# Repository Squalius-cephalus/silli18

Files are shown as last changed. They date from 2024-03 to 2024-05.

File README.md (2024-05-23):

# Silli18
RP2040 based macropad, which uses [QMK](https://github.com/qmk/qmk_firmware) firmware with [Vial](https://get.vial.today/) support. 

If you are interested in macropad with hotswap sockets, check [Silakka18](https://github.com/Squalius-cephalus/silakka18).

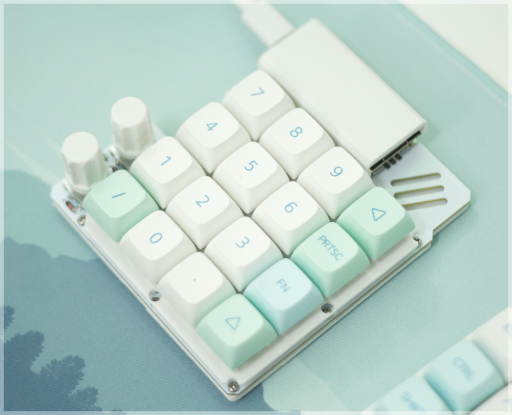
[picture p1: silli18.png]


## Bill of materials

 - 1 x PCB
 - 1 x Pin compatible Raspberry Pi Pico
 - 1 x 3D printed bottom plate
 - 1 x 3D printed top plate
 - 2 x EC11 Rotary encoders
 - 16 x MX style mechanical switches
 - 16 x MX compatible keycaps
 - 18 x 1N4148 diode
 - 8 x M2 4mm bolt
 - 8 x M2 brass inserts 
 - 8x Rubber feet

## TODO

 1. Make build guide

PCB design uses footprints from [ScottoKeebs](https://github.com/joe-scotto/scottokeebs/tree/main/Extras/ScottoKicad "ScottoKeebs") and [kbd library.](https://github.com/foostan/kbd "kbd library.")

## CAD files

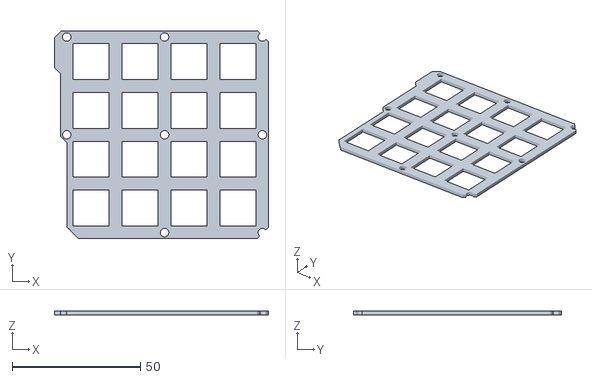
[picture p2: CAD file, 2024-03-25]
stl/top.stl
83.3 x 81.2 x 1.60

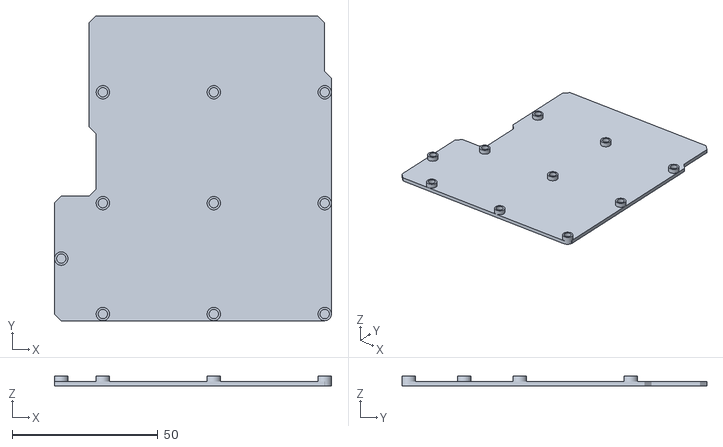
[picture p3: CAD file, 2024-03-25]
stl/bottom.stl
95.3 x 104.8 x 3.60

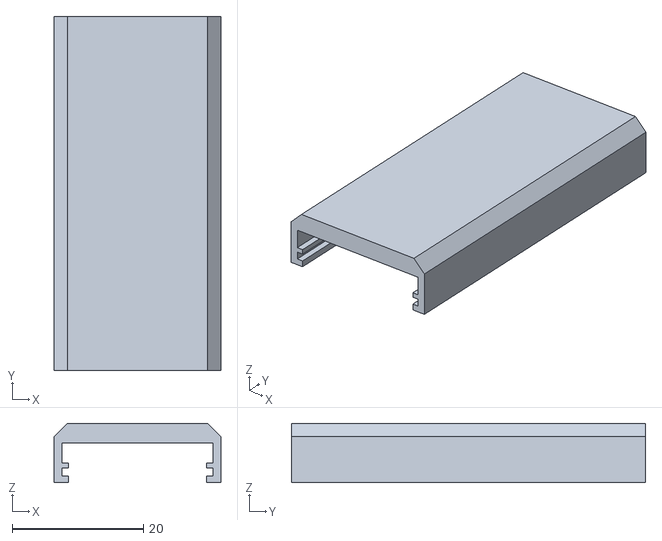
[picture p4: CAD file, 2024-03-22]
stl/raspberry_pi_pico_cover.stl
25.4 x 54.0 x 9.00

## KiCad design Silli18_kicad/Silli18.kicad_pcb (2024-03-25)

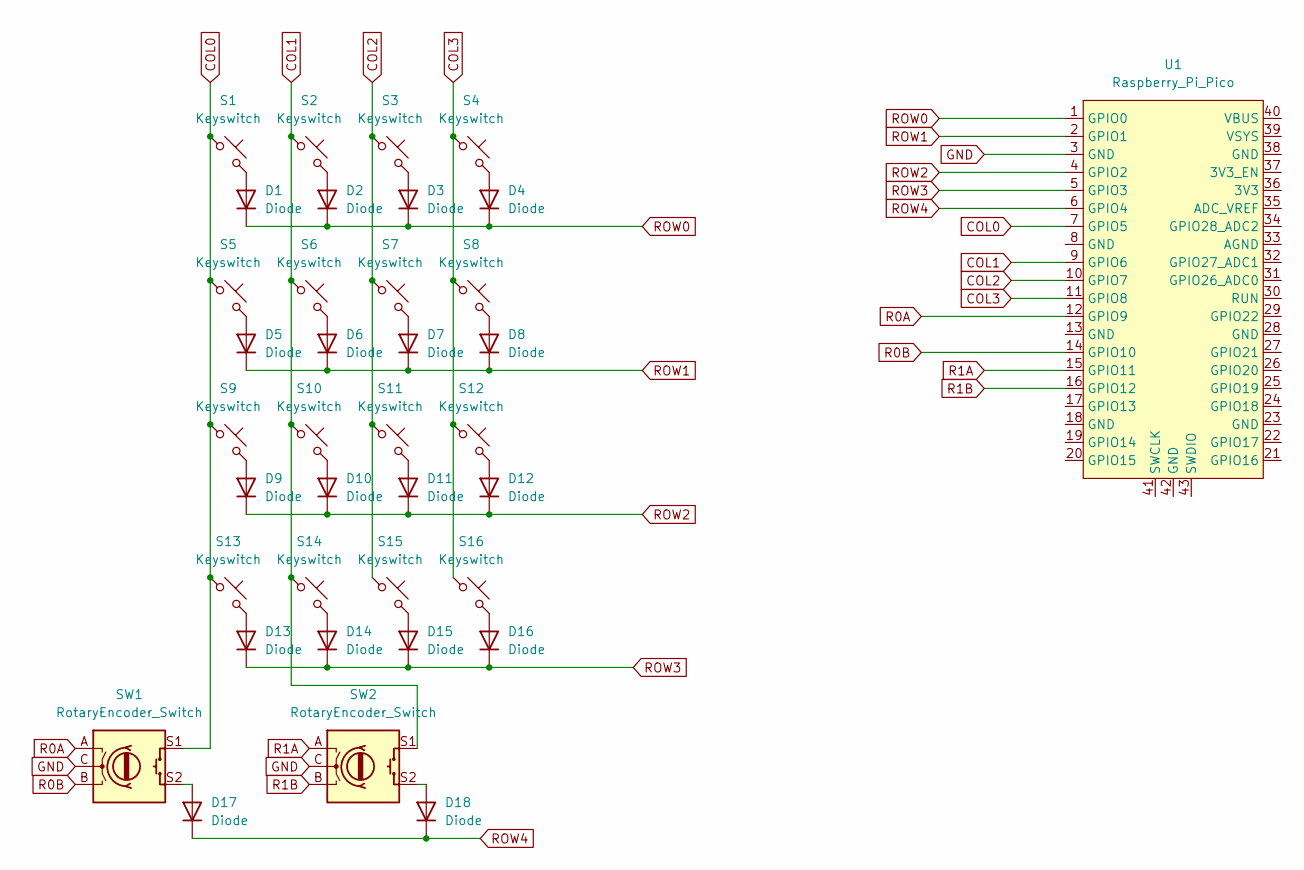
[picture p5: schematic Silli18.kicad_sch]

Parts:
D1, D2, D3, D4, D5, D6, D7, D8, D9, D10, D11, D12, D13, D14, D15, D16, D17, D18: Diode; D3_TH
S1, S2, S3, S4, S5, S6, S7, S8, S9, S10, S11, S12, S13, S14, S15, S16: Keyswitch; MX_PCB_1.00u
SW1, SW2: RotaryEncoder_Switch; RotaryEncoder_EC11
U1: Raspberry_Pi_Pico

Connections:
COL0: S1.1, S5.1, S9.1, S13.1, SW1.S1, U1.7 (GPIO5)
COL1: S2.1, S6.1, S10.1, S14.1, SW2.S1, U1.9 (GPIO6)
COL2: S3.1, S7.1, S11.1, S15.1, U1.10 (GPIO7)
COL3: S4.1, S8.1, S12.1, S16.1, U1.11 (GPIO8)
GND: SW1.C, SW2.C, U1.3 (GND)
unnamed: D1.2 (A), S1.2
unnamed: D2.2 (A), S2.2
unnamed: D3.2 (A), S3.2
unnamed: D4.2 (A), S4.2
unnamed: D5.2 (A), S5.2
unnamed: D6.2 (A), S6.2
unnamed: D7.2 (A), S7.2
unnamed: D8.2 (A), S8.2
unnamed: D9.2 (A), S9.2
unnamed: D10.2 (A), S10.2
unnamed: D11.2 (A), S11.2
unnamed: D12.2 (A), S12.2
unnamed: D13.2 (A), S13.2
unnamed: D14.2 (A), S14.2
unnamed: D15.2 (A), S15.2
unnamed: D16.2 (A), S16.2
unnamed: D17.2 (A), SW1.S2
unnamed: D18.2 (A), SW2.S2
R0A: SW1.A, U1.12 (GPIO9)
R0B: SW1.B, U1.14 (GPIO10)
R1A: SW2.A, U1.15 (GPIO11)
R1B: SW2.B, U1.16 (GPIO12)
ROW0: D1.1 (K), D2.1 (K), D3.1 (K), D4.1 (K), U1.1 (GPIO0)
ROW1: D5.1 (K), D6.1 (K), D7.1 (K), D8.1 (K), U1.2 (GPIO1)
ROW2: D9.1 (K), D10.1 (K), D11.1 (K), D12.1 (K), U1.4 (GPIO2)
ROW3: D13.1 (K), D14.1 (K), D15.1 (K), D16.1 (K), U1.5 (GPIO3)
ROW4: D17.1 (K), D18.1 (K), U1.6 (GPIO4)

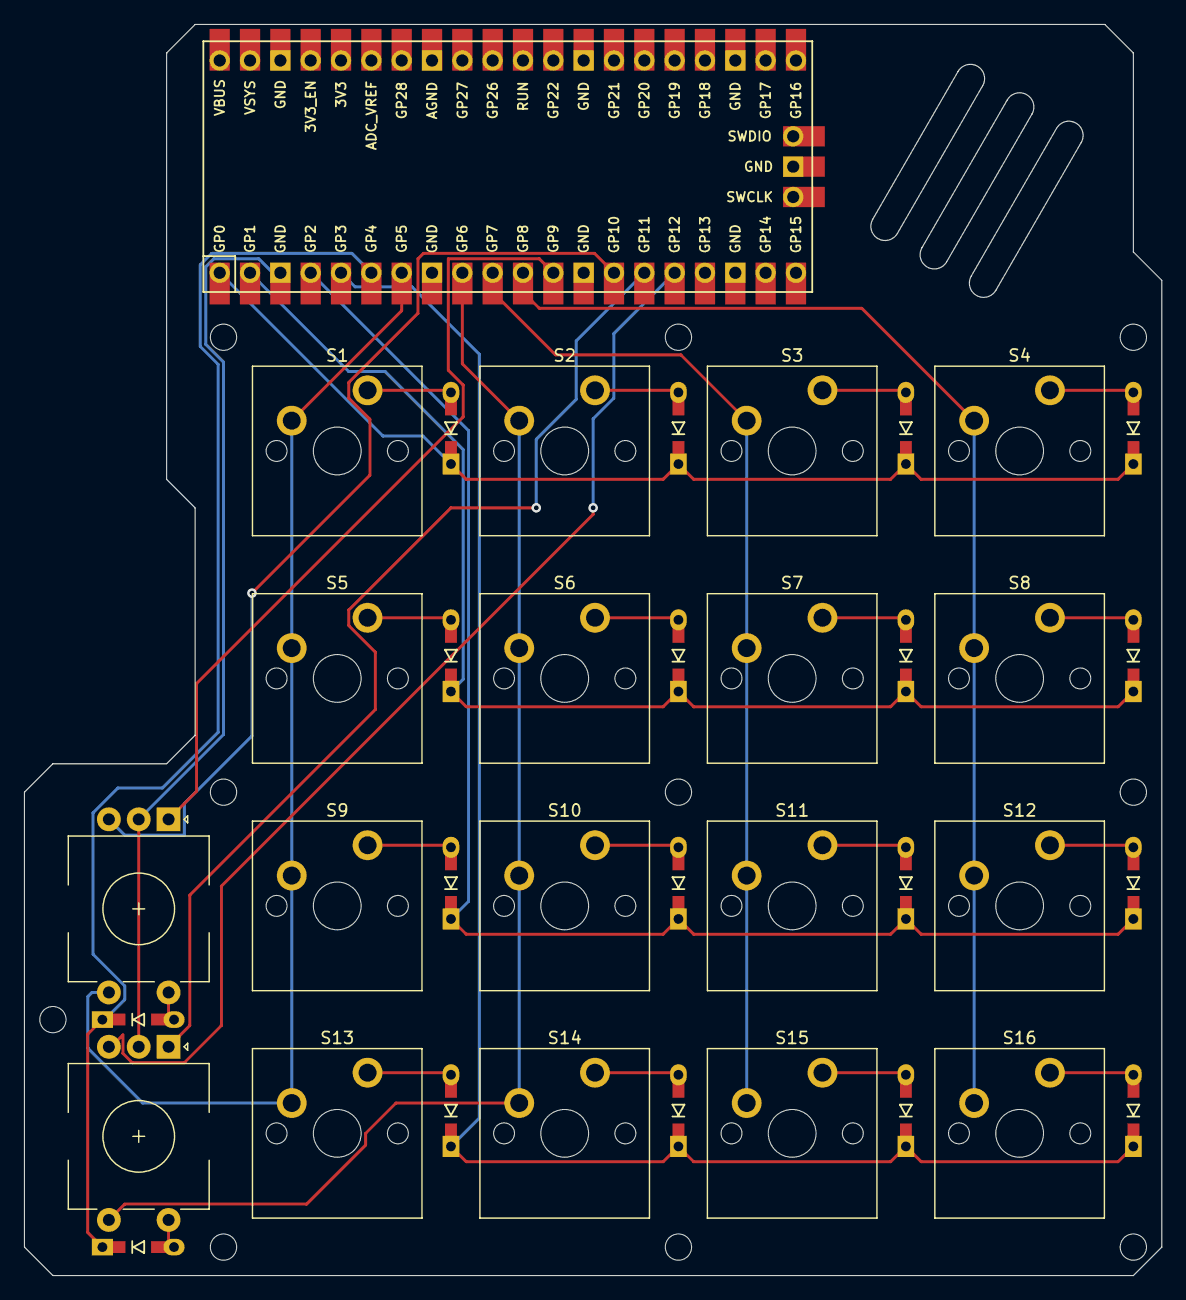
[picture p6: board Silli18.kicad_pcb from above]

Board: 2 copper layers, 95.2 x 104.8 mm, 37 parts (0 on the bottom side), 32 nets.

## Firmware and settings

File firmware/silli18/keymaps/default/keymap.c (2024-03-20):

// Copyright 2023 QMK
// SPDX-License-Identifier: GPL-2.0-or-later

#include QMK_KEYBOARD_H

const uint16_t PROGMEM keymaps[][MATRIX_ROWS][MATRIX_COLS] = {
    /*
     * ┌───┬───┬───┬───┐
     * │ 7 │ 8 │ 9 │ / │
     * ├───┼───┼───┼───┤
     * │ 4 │ 5 │ 6 │ * │
     * ├───┼───┼───┼───┤
     * │ 1 │ 2 │ 3 │ - │
     * ├───┼───┼───┼───┤
     * │ 0 │ . │Ent│ + │
     * └───┴───┴───┴───┘
     */
    [0] = LAYOUT_ortho_4x5(
        KC_P7,   KC_P8,   KC_P9,   KC_PSLS,
        KC_P4,   KC_P5,   KC_P6,   KC_PAST,
        KC_P1,   KC_P2,   KC_P3,   KC_PMNS,
        KC_P0,   KC_PDOT, KC_PENT, KC_PPLS,
        KC_P0,   KC_PDOT, KC_NO	, KC_NO	
    )
};

#if defined(ENCODER_MAP_ENABLE)
const uint16_t PROGMEM encoder_map[][NUM_ENCODERS][2] = {
    [0] =   { ENCODER_CCW_CW(KC_A, KC_B), ENCODER_CCW_CW(KC_D, KC_F)  }
    //                  Encoder 1                                     Encoder 2
};
#endif

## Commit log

2024-03-17 Added STL and gerber files
    [bottom.stl, top.stl]
2024-03-25 Added KiCAD files
    [Silli18.kicad_pcb, Silli18.kicad_sch]
2024-03-25 Fixed STL files scale.
    [bottom.stl, top.stl]
2024-05-23 Update README.md
    Fixed BOM
